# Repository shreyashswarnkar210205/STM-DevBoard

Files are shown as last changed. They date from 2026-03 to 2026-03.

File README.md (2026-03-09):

# ⚡ STM-OWN – Custom STM32 Development Board

Custom STM32-based development board designed in **KiCad** for learning and experimenting with embedded systems and PCB design.

This project demonstrates the complete PCB design workflow including schematic design, PCB layout, custom footprint creation, and hardware documentation.

---

## 🧠 Project Overview

**STM-OWN** is a custom STM32 development board inspired by common development boards such as Bluepill and Nucleo boards.

The objective of this project was to practice:

- STM32 hardware design
- Schematic capture
- PCB layout and routing
- Creating custom KiCad libraries
- Generating manufacturing-ready files
- Hardware documentation

This board can be used for:

- Embedded firmware development
- Peripheral interfacing
- Learning STM32 architecture
- Rapid prototyping

---

## 🛠 Tools Used

- **KiCad** – Schematic capture and PCB design
- **Custom symbol libraries**
- **Custom footprint libraries**
- **Git & GitHub** – Version control
- **PDF exports** – Documentation

---

## 🏗 PCB Design

Features of the board include:

- STM32 microcontroller core
- GPIO breakout headers
- Power regulation circuitry
- Programming/debug interface
- User interface components (buttons / LEDs)

Design considerations:

- Proper decoupling capacitors
- Clean power routing
- Ground plane usage
- Optimized component placement
- Design Rule Check (DRC) compliance

---

## 🖼 Board Preview

### Front View
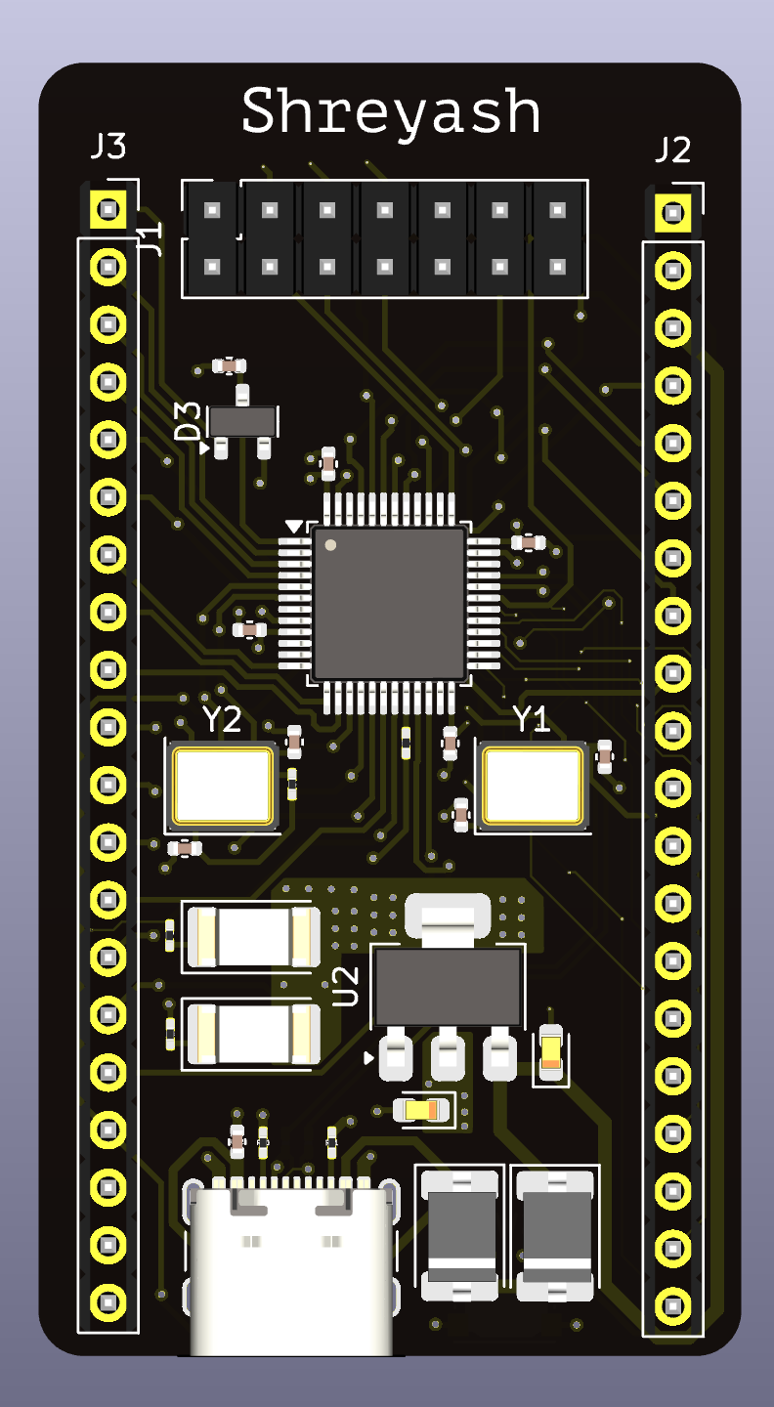
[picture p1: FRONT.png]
Front


### Back View
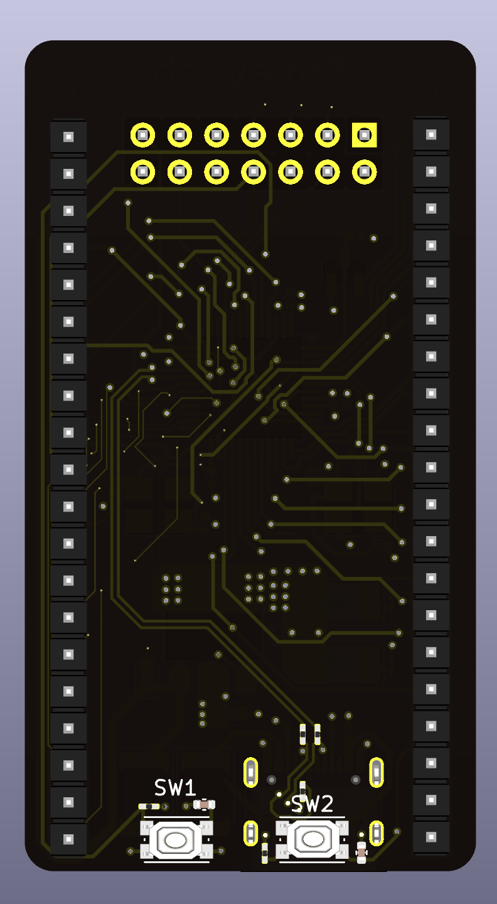
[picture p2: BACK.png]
Back


### 3D View
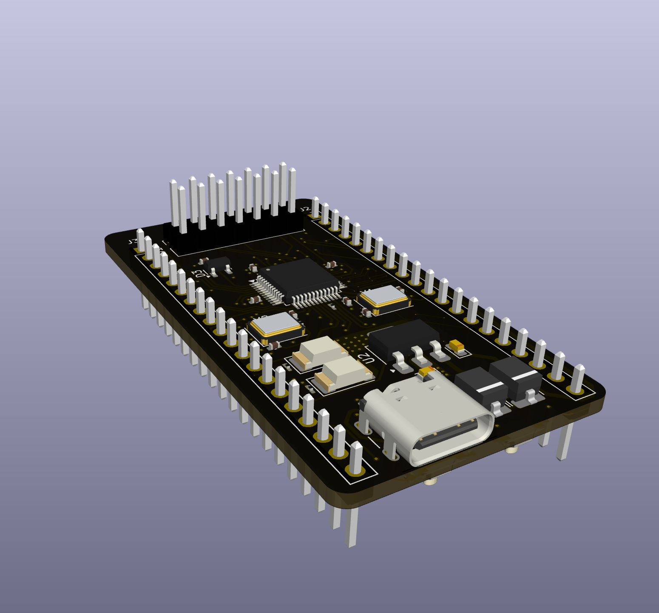
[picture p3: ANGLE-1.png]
Angle


---

## 📂 Repository Structure
STM-OWN
│
├── Main/ # KiCad project files
│ ├── Main.kicad_pcb
│ ├── Main.kicad_pro
│ └── backups/
│
├── SIGN.pretty/ # Custom footprint library
│
├── FRONT.png # PCB front render
├── BACK.png # PCB back render
├── ANGLE-1.png # 3D board view
├── ANGLE-2.png # 3D board view
│
├── Schematic.pdf # Full schematic
├── Layout.pdf # PCB layout documentation
├── Basic.pdf # Design notes
│
└── README.md

---

## 📑 Documentation

Included design documentation:

- **Schematic.pdf** – Full circuit schematic
- **Layout.pdf** – PCB layout visualization
- **Basic.pdf** – Additional design notes

These files allow quick viewing of the design without opening KiCad.

---

## 🎯 Learning Outcomes

Through this project:

- Designed a complete STM32 hardware platform
- Learned PCB routing and layout techniques
- Created custom KiCad footprints and symbols
- Generated fabrication-ready design files
- Practiced professional hardware documentation

---

## 🚀 Future Improvements

Possible upgrades for the next revision:

- Add USB programming interface
- Add SWD debugging header
- Improve power regulation efficiency
- Add additional peripheral connectors
- Convert to a 4-layer PCB design

---

## 📜 License

This project is open hardware and available for educational and experimental use.

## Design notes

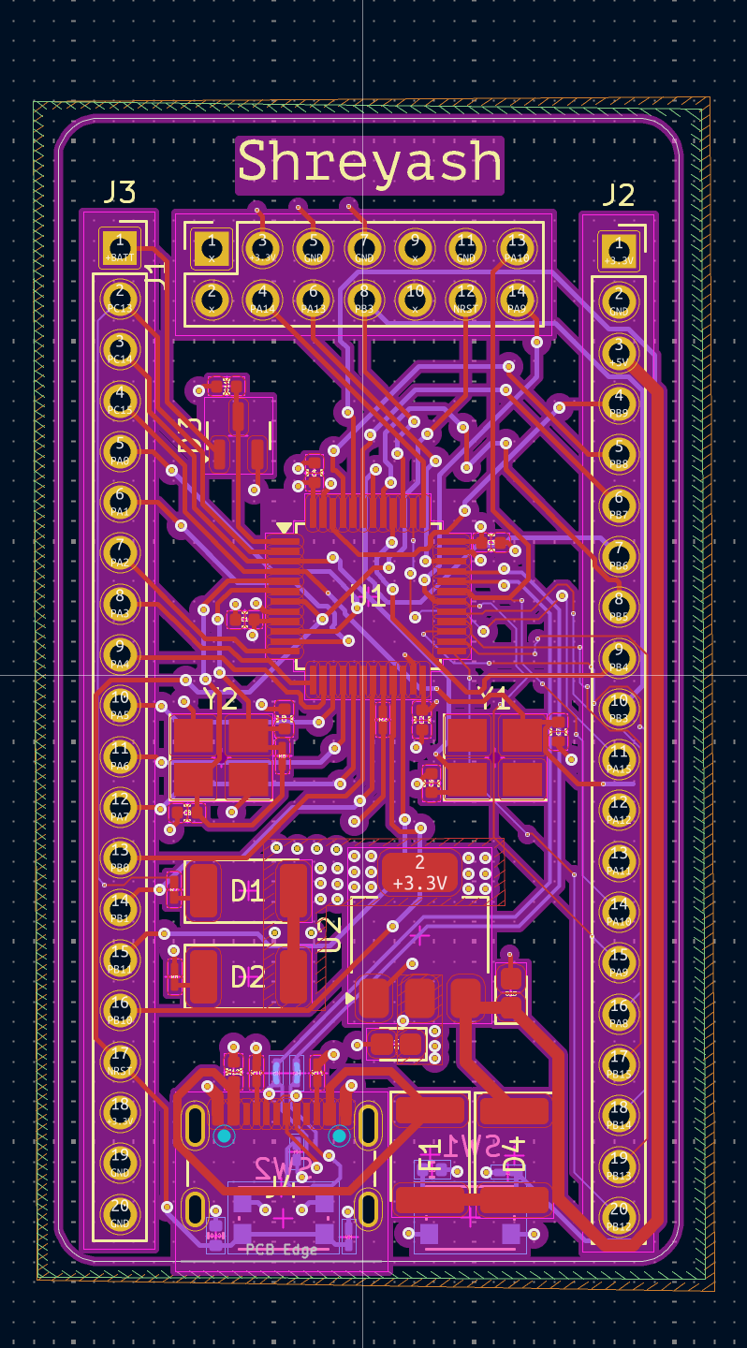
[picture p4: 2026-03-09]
LAYOUT.png

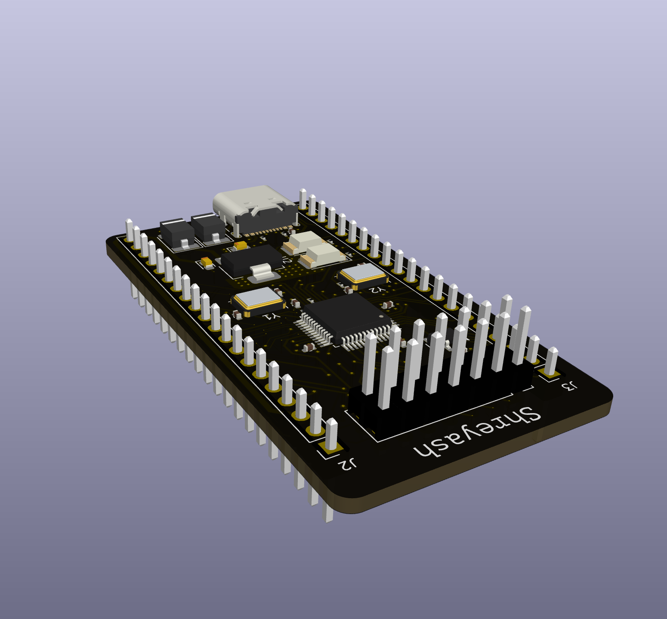
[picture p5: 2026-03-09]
ANGLE-2.png

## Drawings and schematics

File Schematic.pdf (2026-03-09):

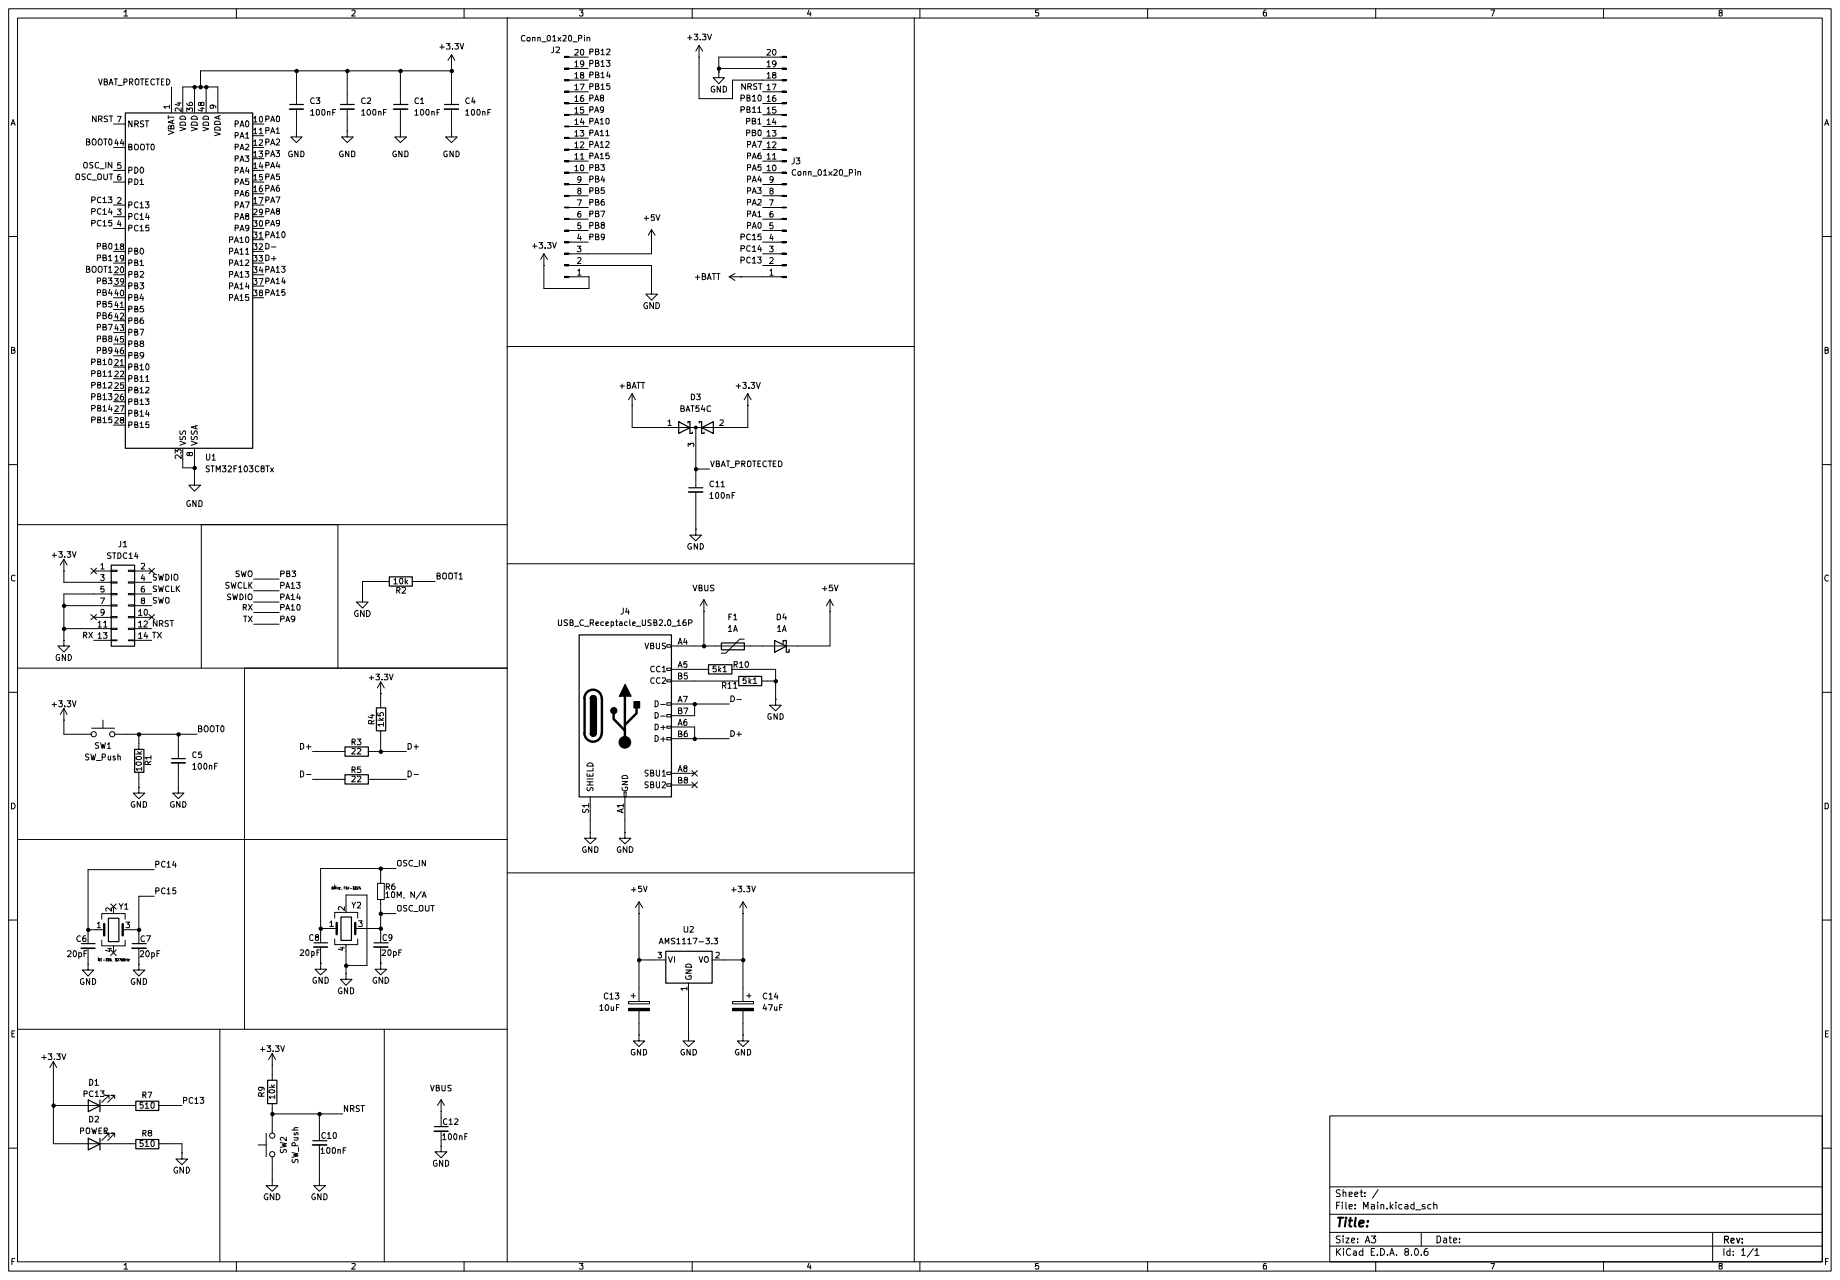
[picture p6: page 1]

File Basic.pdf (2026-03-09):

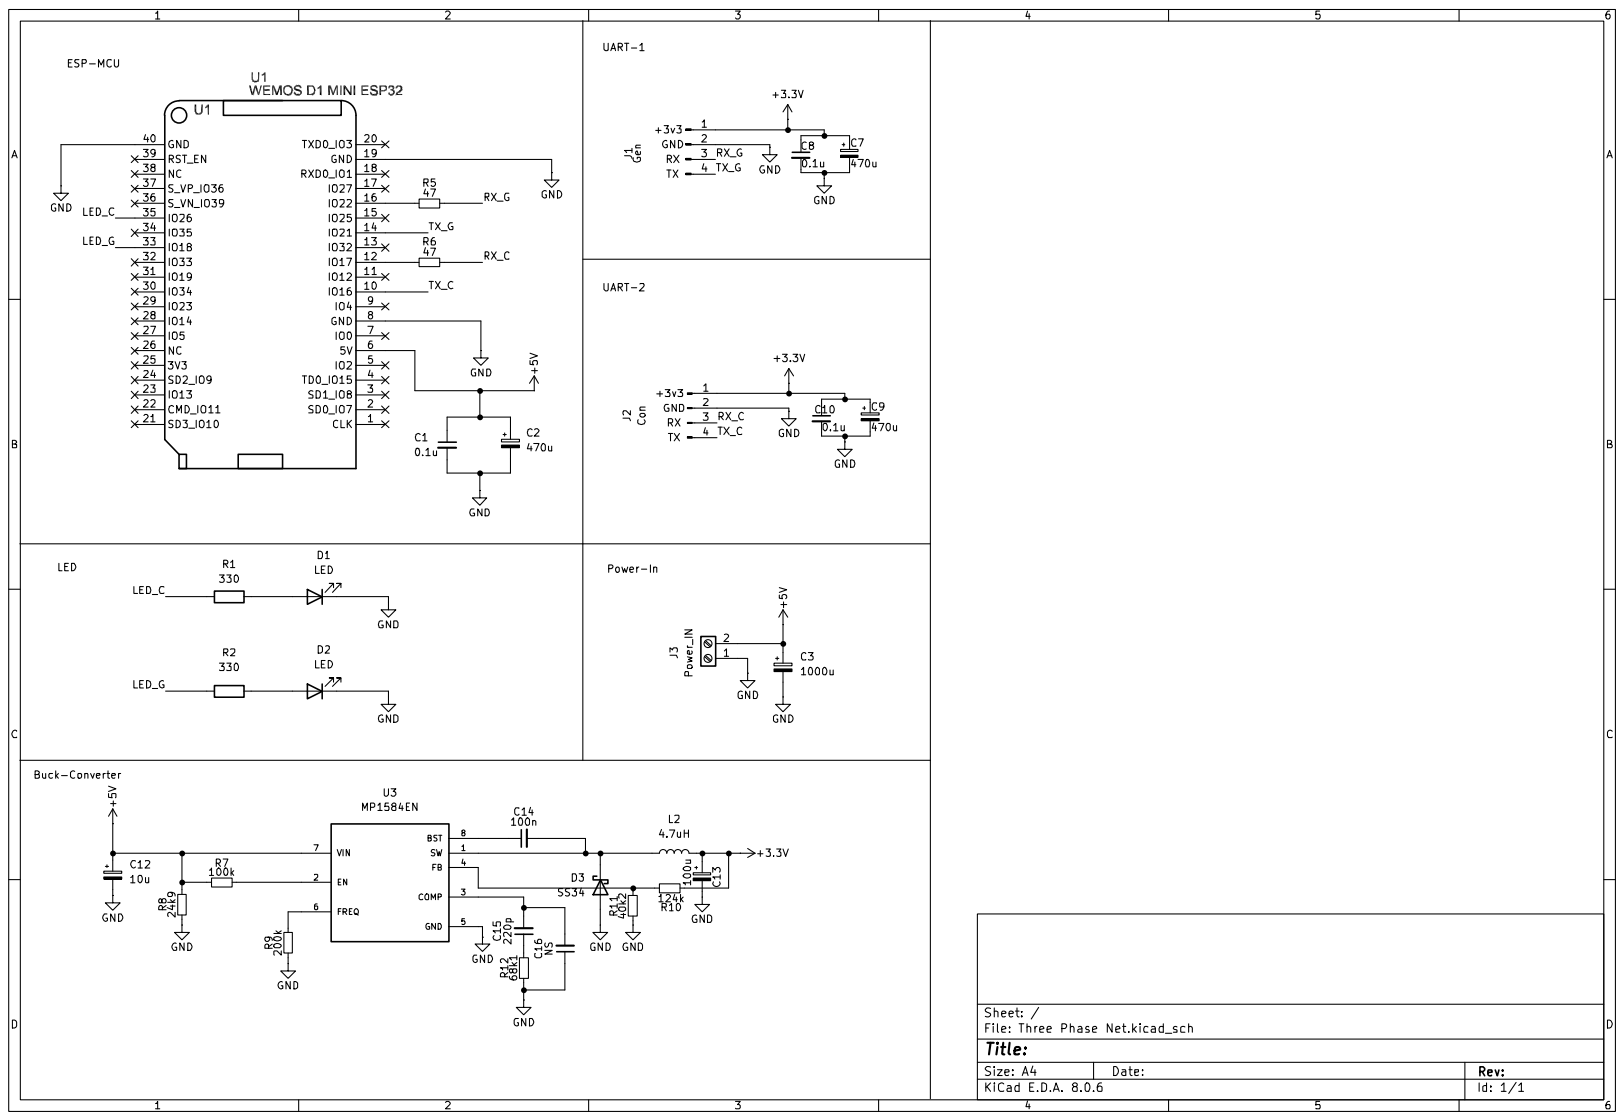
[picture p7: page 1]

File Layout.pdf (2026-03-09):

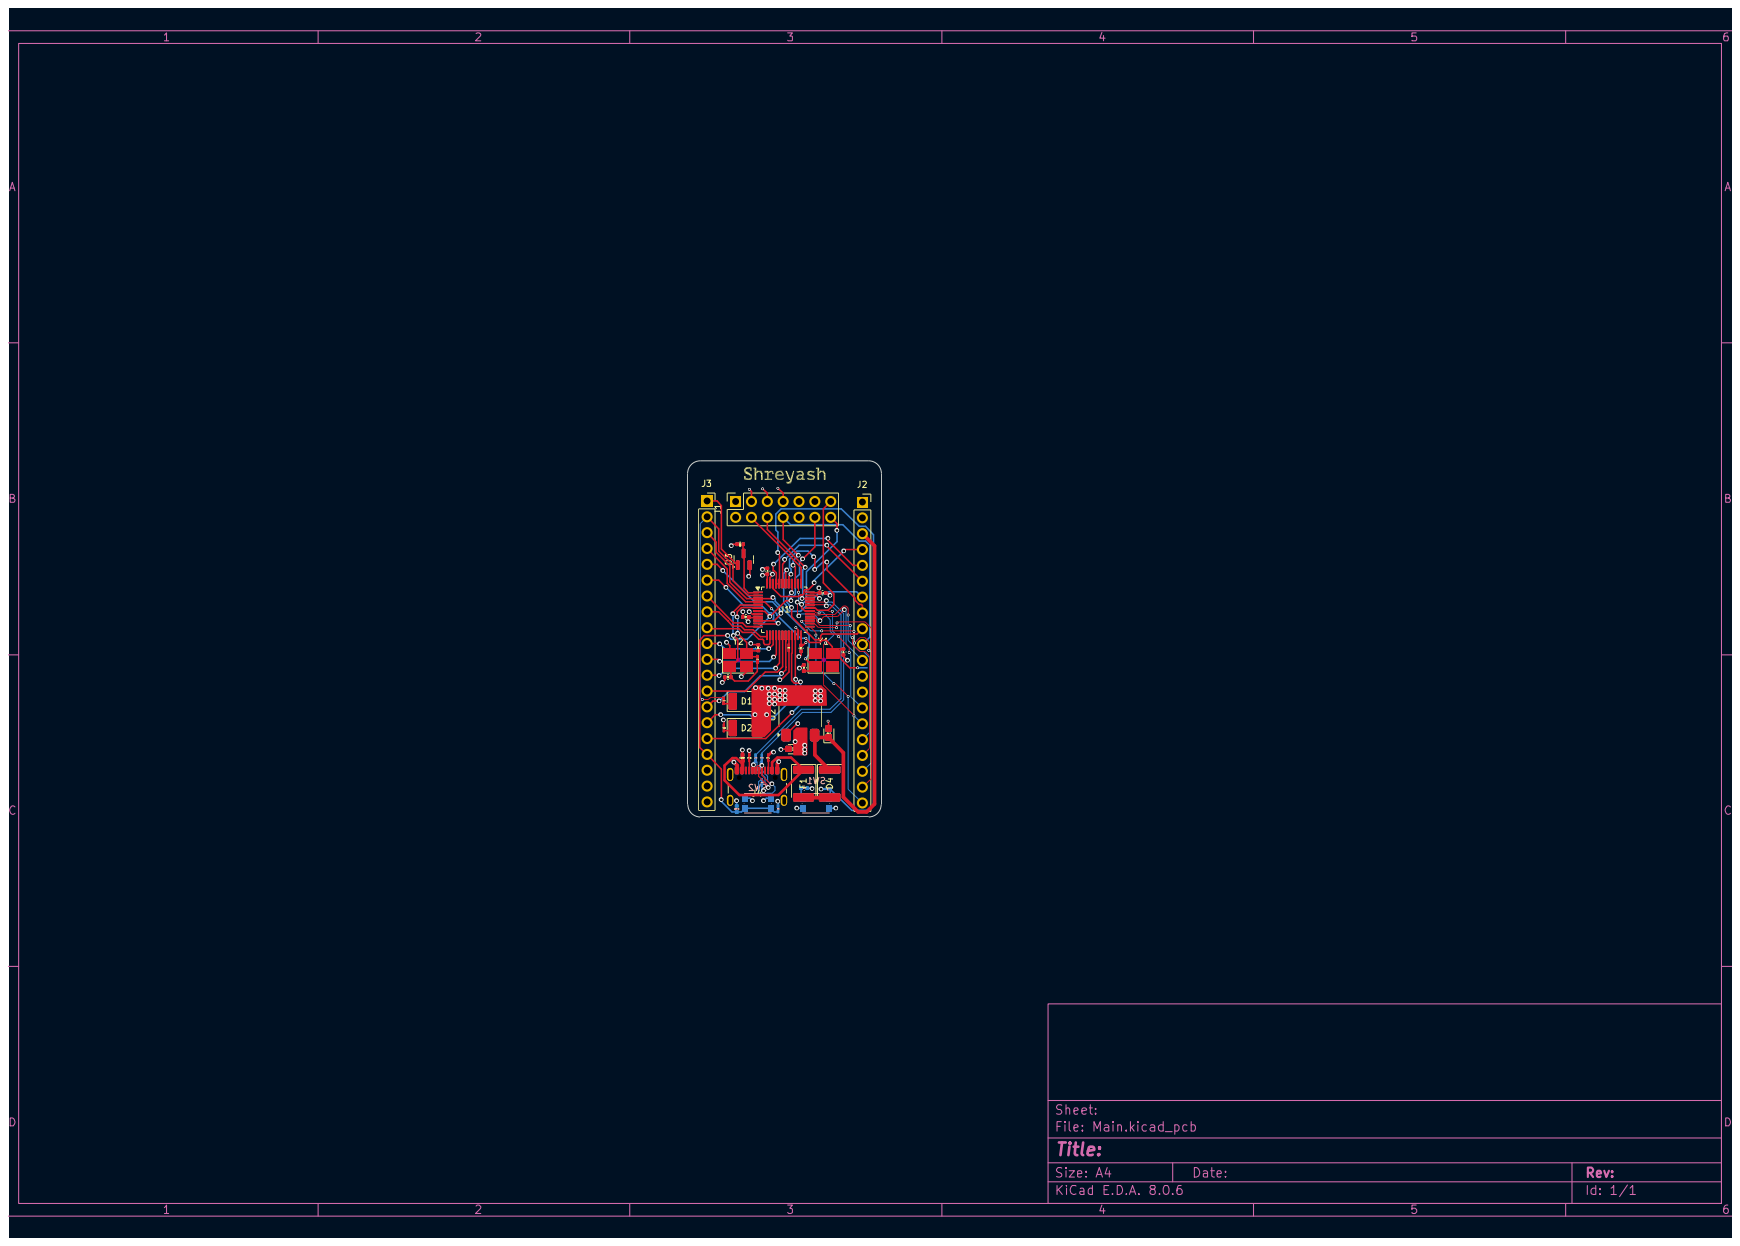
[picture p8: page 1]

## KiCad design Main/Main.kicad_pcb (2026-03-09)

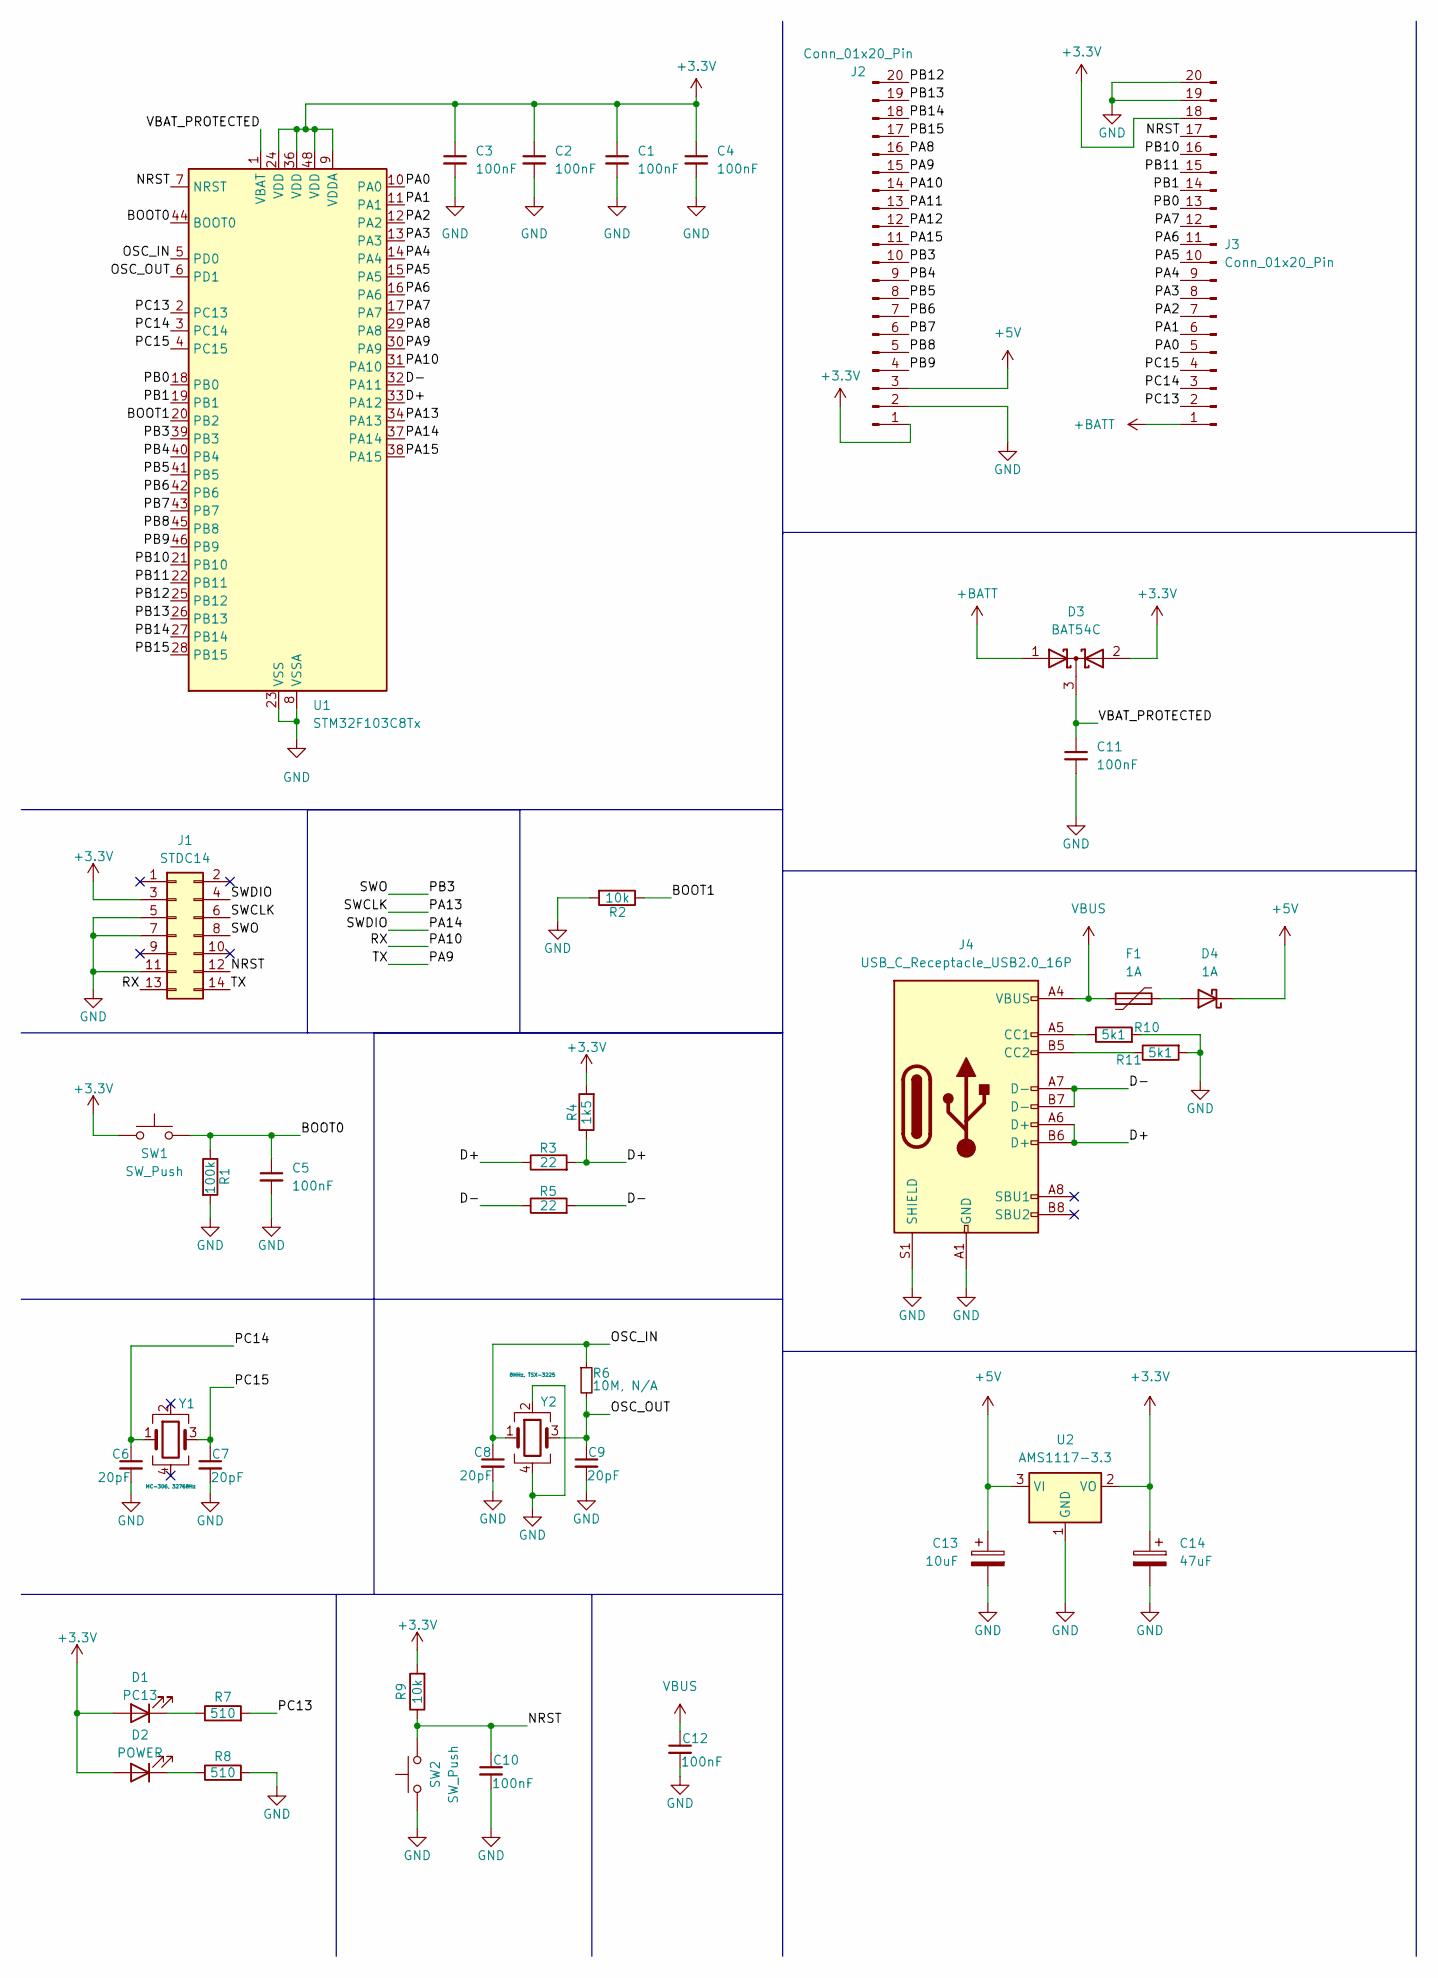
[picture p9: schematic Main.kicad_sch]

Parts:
C1, C2, C3, C4, C5, C10, C11, C12: 100nF; C_0402_1005Metric
C6, C7, C8, C9: 20pF; C_0402_1005Metric
C13: 10uF; CP_EIA-1608-08_AVX-J
C14: 47uF; CP_EIA-1608-08_AVX-J
D1: PC13; LED_2010_5025Metric
D2: POWER; LED_2010_5025Metric
D3: BAT54C; SOT-23
D4: 1A; D_1812_4532Metric_Pad1.30x3.40mm_HandSolder
F1: 1A; D_1812_4532Metric_Pad1.30x3.40mm_HandSolder
J1: STDC14; PinSocket_2x07_P2.54mm_Vertical
J2, J3: Conn_01x20_Pin; PinSocket_1x20_P2.54mm_Vertical
J4: USB_C_Receptacle_USB2.0_16P; USB_C_Receptacle_GCT_USB4105-xx-A_16P_TopMnt_Horizontal
R1: 100k; R_0201_0603Metric_Pad0.64x0.40mm_HandSolder
R2, R9: 10k; R_0201_0603Metric_Pad0.64x0.40mm_HandSolder
R3, R5: 22; R_0201_0603Metric_Pad0.64x0.40mm_HandSolder
R4: 1k5; R_0201_0603Metric_Pad0.64x0.40mm_HandSolder
R6: 10M, N/A; R_0201_0603Metric_Pad0.64x0.40mm_HandSolder
R7, R8: 510; R_0201_0603Metric_Pad0.64x0.40mm_HandSolder
R10, R11: 5k1; R_0201_0603Metric_Pad0.64x0.40mm_HandSolder
SW1, SW2: SW_Push; SW_Push_1P1T_NO_CK_KMR2
U1: STM32F103C8Tx; LQFP-48_7x7mm_P0.5mm
U2: AMS1117-3.3; SOT-223-3_TabPin2
Y1: MC-306, 32768Hz; Oscillator_SMD_Abracon_ASE-4Pin_3.2x2.5mm_HandSoldering
Y2: 8MHz, TSX-3225; Oscillator_SMD_Abracon_ASE-4Pin_3.2x2.5mm_HandSoldering

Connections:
+3.3V: C1.1, C2.1, C3.1, C4.1, C14.1, D1.2 (A), D2.2 (A), D3.2 (A), J1.3, J2.1, J3.18, R4.2, R9.2, SW1.1, U1.9 (VDDA), U1.24 (VDD), U1.36 (VDD), U1.48 (VDD), U2.2 (VO)
+5V: C13.1, D4.1 (K), J2.3, U2.3 (VI)
+BATT: D3.1 (A), J3.1
/BOOT0: C5.1, R1.1, SW1.2, U1.44 (BOOT0)
/BOOT1: R2.1, U1.20 (PB2)
/D+: J4.A6 (D+), J4.B6 (D+), R3.1, R3.2, R4.1, U1.33 (PA12)
/D-: J4.A7 (D-), J4.B7 (D-), R5.1, R5.2, U1.32 (PA11)
/NRST: C10.1, J1.12, J3.17, R9.1, SW2.2, U1.7 (NRST)
/OSC_IN: C8.1, R6.1, U1.5 (PD0), Y2.1
/OSC_OUT: C9.1, R6.2, U1.6 (PD1), Y2.3
/PA0: J3.5, U1.10 (PA0)
/PA1: J3.6, U1.11 (PA1)
/PA2: J3.7, U1.12 (PA2)
/PA3: J3.8, U1.13 (PA3)
/PA4: J3.9, U1.14 (PA4)
/PA5: J3.10, U1.15 (PA5)
/PA6: J3.11, U1.16 (PA6)
/PA7: J3.12, U1.17 (PA7)
/PA8: J2.16, U1.29 (PA8)
/PA9: J1.14, J2.15, U1.30 (PA9)
/PA10: J1.13, J2.14, U1.31 (PA10)
/PA11: J2.13
/PA12: J2.12
/PA13: J1.6, U1.34 (PA13)
/PA14: J1.4, U1.37 (PA14)
/PA15: J2.11, U1.38 (PA15)
/PB0: J3.13, U1.18 (PB0)
/PB1: J3.14, U1.19 (PB1)
/PB3: J1.8, J2.10, U1.39 (PB3)
/PB4: J2.9, U1.40 (PB4)
/PB5: J2.8, U1.41 (PB5)
/PB6: J2.7, U1.42 (PB6)
/PB7: J2.6, U1.43 (PB7)
/PB8: J2.5, U1.45 (PB8)
/PB9: J2.4, U1.46 (PB9)
/PB10: J3.16, U1.21 (PB10)
/PB11: J3.15, U1.22 (PB11)
/PB12: J2.20, U1.25 (PB12)
/PB13: J2.19, U1.26 (PB13)
/PB14: J2.18, U1.27 (PB14)
/PB15: J2.17, U1.28 (PB15)
/PC13: J3.2, R7.2, U1.2 (PC13)
/PC14: C6.1, J3.3, U1.3 (PC14), Y1.1
/PC15: C7.1, J3.4, U1.4 (PC15), Y1.3
/VBAT_PROTECTED: C11.1, D3.3 (K), U1.1 (VBAT)
GND: C1.2, C2.2, C3.2, C4.2, C5.2, C6.2, C7.2, C8.2, C9.2, C10.2, C11.2, C12.2, C13.2, C14.2, J1.5, J1.7, J1.11, J2.2, J3.19, J3.20, J4.A1 (GND), J4.A12 (GND), J4.B1 (GND), J4.B12 (GND), J4.S1 (SHIELD), R1.2, R2.2, R8.2, R10.2, R11.2, SW2.1, U1.8 (VSSA), U1.23 (VSS), U1.35 (VSS), U1.47 (VSS), U2.1 (GND), Y2.2, Y2.4
unnamed: D1.1 (K), R7.1
unnamed: D2.1 (K), R8.1
unnamed: D4.2 (A), F1.2
unnamed: J4.A5 (CC1), R10.1
unnamed: J4.B5 (CC2), R11.1
VBUS: C12.1, F1.1, J4.A4 (VBUS), J4.A9 (VBUS), J4.B4 (VBUS), J4.B9 (VBUS)

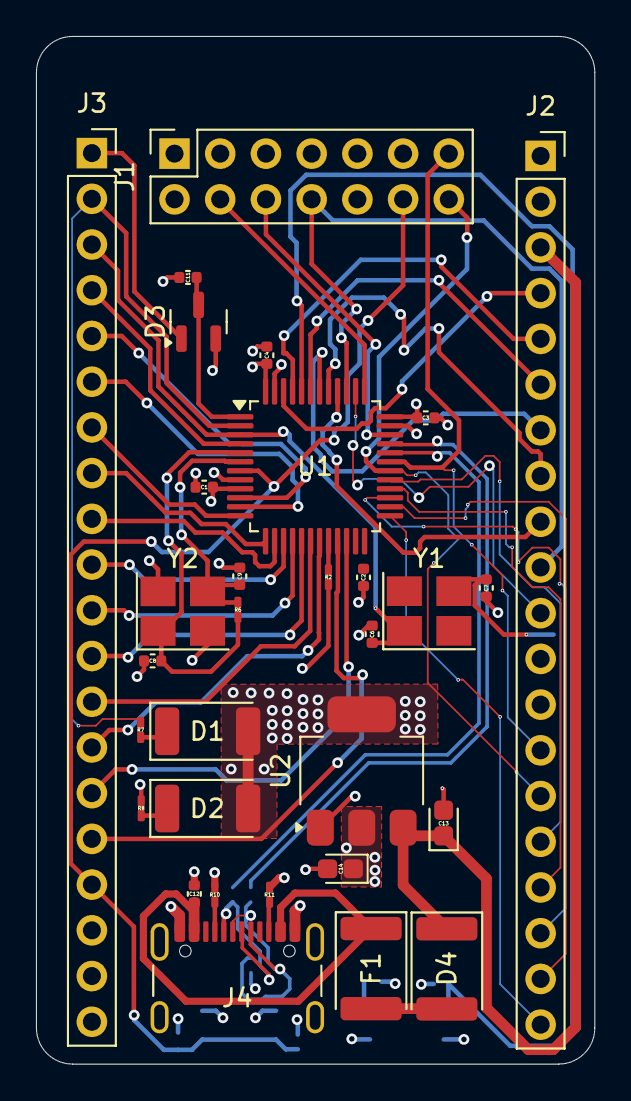
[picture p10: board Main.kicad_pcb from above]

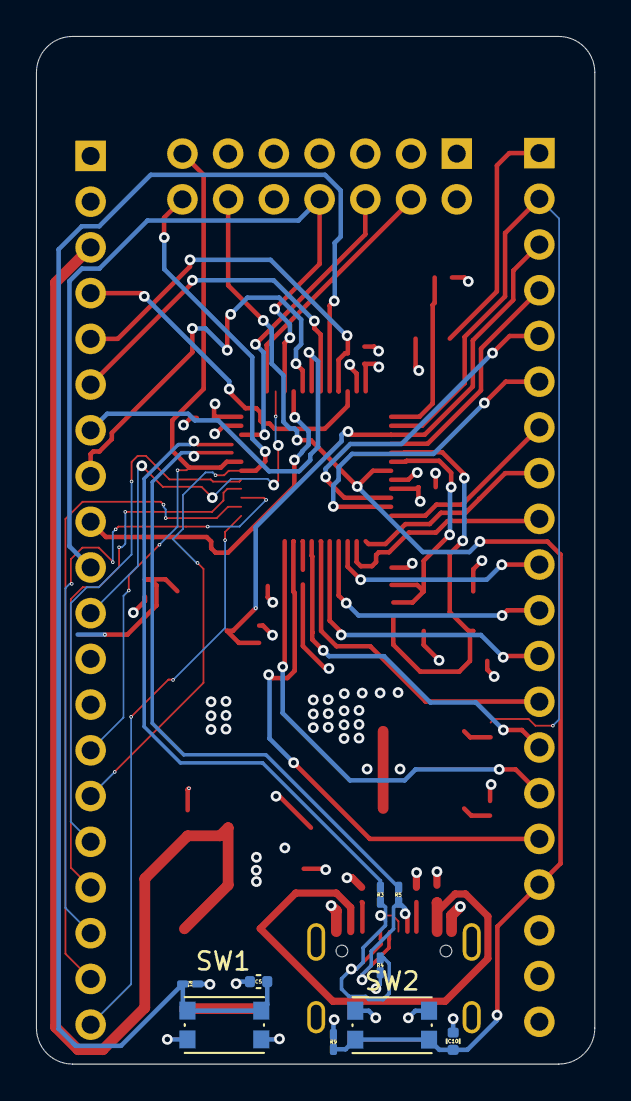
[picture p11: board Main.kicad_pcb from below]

Board: 4 copper layers, 31.0 x 57.1 mm, 40 parts (9 on the bottom side), 50 nets.
